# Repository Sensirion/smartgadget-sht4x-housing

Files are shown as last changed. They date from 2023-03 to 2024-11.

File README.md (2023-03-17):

# SHT4x Smartgadget Housing

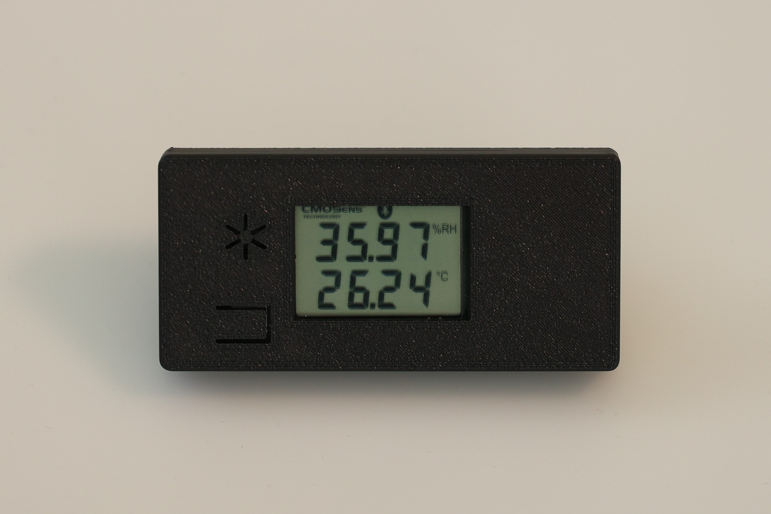
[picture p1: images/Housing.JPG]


## Introduction

The SHT4x Smartgadget is a simple reference design circuit board which demonstrates the outstanding performance and ease of use of Sensirion’s SHT4x Humidity and Temperature sensors. It is equipped with a Liquid Crystal Display (LCD) showing humidity and temperature information. It also features a Bluetooth connection which can be used by smartphones. If you want to buy this gadget or find more information about this sensor, please go to our [Website](https://sensirion.com/products/catalog/SHT4x-Smart-Gadget/).

Since the sensor on the SHT4x Smartgadget is very exposed, a housing was created to better protect it. This guide will show you how to assemble the housing for the SHT4x Smartgadget in order to place it somewhere on your wall or on your desk. In addition, there follows a short sequence describing the influence of the case on the sensor's measurement and what to expect from the SHT4x Smartgadget in the housing. Thus, the guide is structured in these parts:

* [Hardware Setup](#hardware-setup)
    * [Step by Step Assembly](#step-by-step-assembly)
* [Mechanical Integration](#mechanical-integration)
* [Housing Influence on Sensor Reading](#housing-influence-on-sensor-reading)
    * [Introduction](#introduction)
    * [Accuracy](#accuracy)
    * [Response Time](#response-time)

## Hardware Setup

To complete this tutorial you will need:

* SHT4x Smart Gadget
* 3D printed housing of the gadget, consisting of 3 parts (Front, Back and Wall Mount). You can print all these parts yourself (STL files are in the folder "Housing")

### Step by Step Assembly

1. Have the SHT4x Smartgadget (1) ready for assembly and print the Front (2), Back (3) and Wall Mount (4) of the housing:

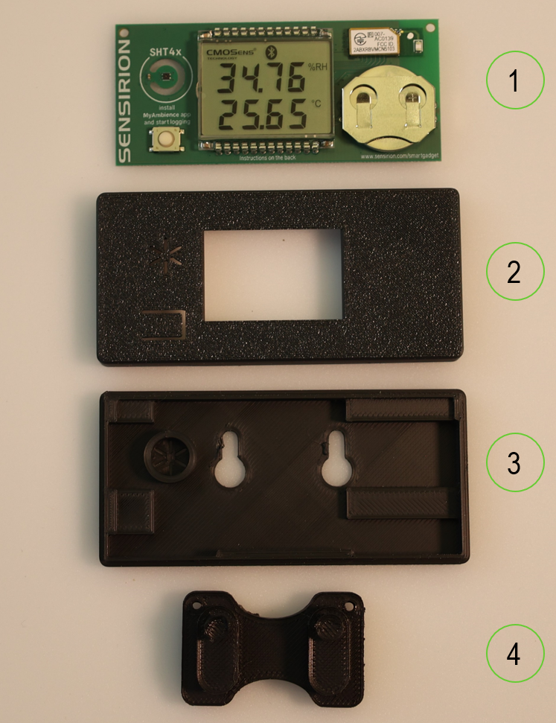
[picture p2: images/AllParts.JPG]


2. Fit the SHT4x Smartgadget into the back wall of the printed housing:

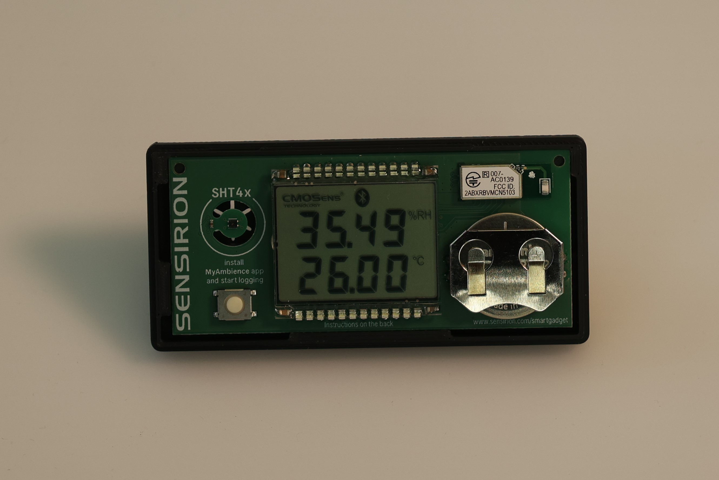
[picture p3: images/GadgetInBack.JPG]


3. Close the housing with the front part:



4. In the end, the wall mount can be attached to the opening at the back and either be attached to the wall or simply used as a stand on your desk:

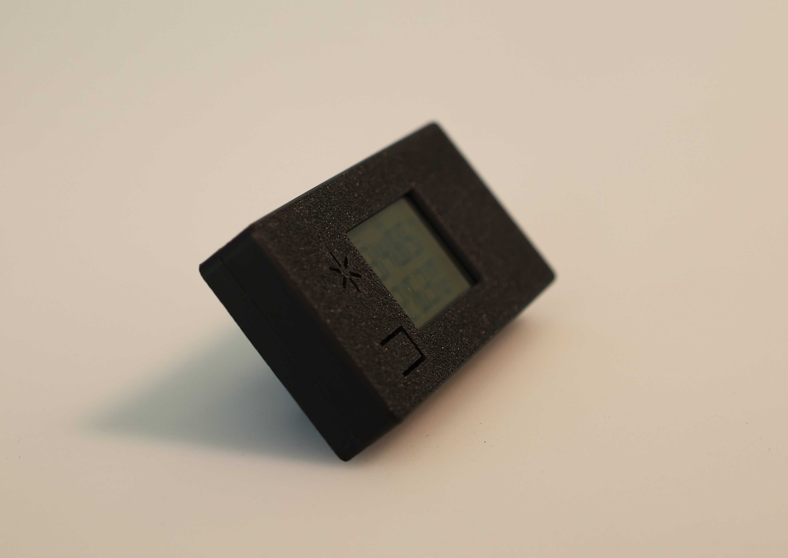
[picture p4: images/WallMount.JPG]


## Mechanical Integration

In order to design such a housing, different requirements need to be met. Firstly and foremost, the sensor readings should be affected minimally by the housing. To do this, the general guide for temperature sensors was followed. The full guide can be found on the [Sensirion Website](https://sensirion.com/media/documents/FC5BED84/61644655/Sensirion_Temperature_Sensors_Design_Guide_V1.pdf). In general, a few things need to be considered. Primarily, the sensor needs to have good access to the environment to allow for air exchange. In addition, the sensor should be sealed from the rest of the compartment to minimize the influence of trapped air inside the housing and only measure the ambient air flow, meaning it should also be decoupled from heat sources like e.g. a microcontroller or the power electronics.

As can be seen from the bare SHT4x Smartgadget Housing in this first picture, the sensor is perfectly decoupled from the rest. The cut-out around the sensor separates the sensor from the rest, hence, allowing for optimal air flow.

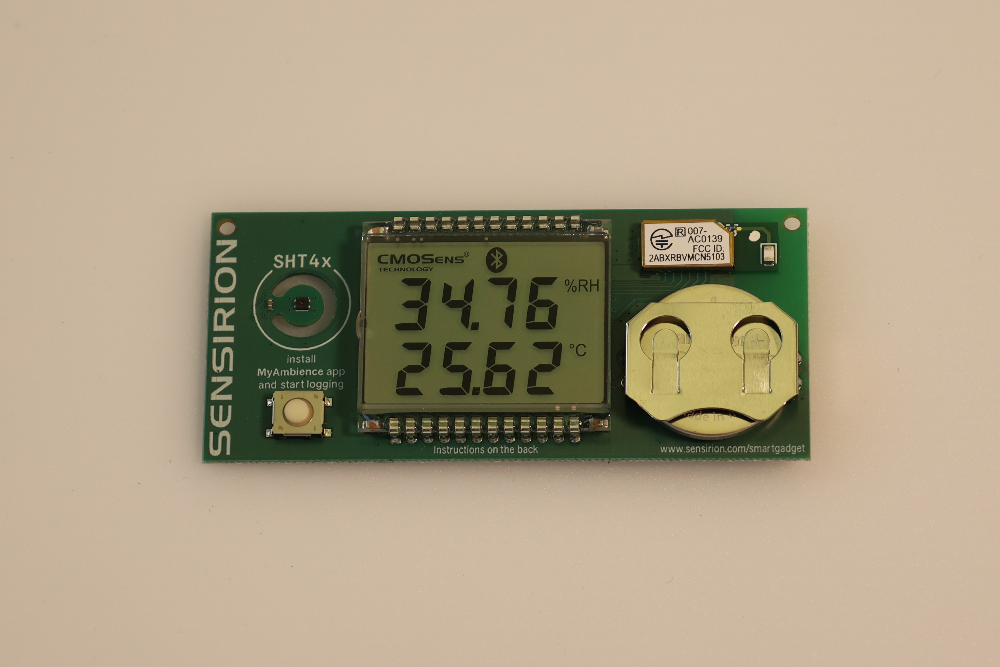
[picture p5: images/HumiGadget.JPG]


To ensure that this encapsulation still holds in the housing, a cylinder was implemented around the sensor. With this implementation, the sensor should only be affected by the ambient conditions. As it was not clear what design of the opening was better for the specifications from the beginning, two designs were made. One which is optically more pleasing with a flower pattern and another one with a hole to guarantee enough air flow to the sensor. Both designs can be seen in the photos below. Both designs were tested and compared to each other at a later stage to define the final case.


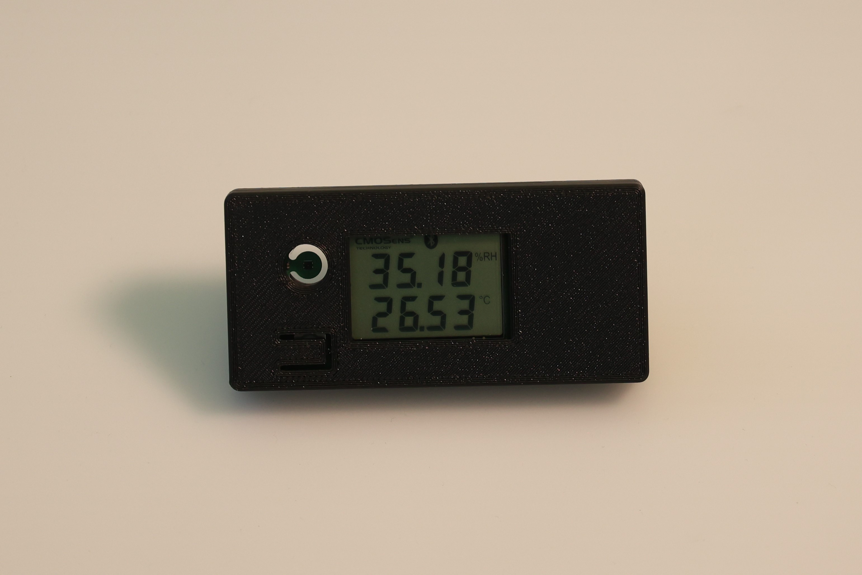
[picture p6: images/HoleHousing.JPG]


## Housing Influence on Sensor Reading

### Introduction

Having a housing around the sensor can influence the accuracy and response time. Thus, the following parts show why and how the sensor readings change due to the housing. Firstly, the accuracy of the sensor might change in a housing depending on how it is coupled to the ambient temperature and how the interaction is between the microcontroller, the power electronics and the sensor itself (especially regarding temperature). In addition, the response time of a sensor can greatly vary when having a case since the housing needs to adapt to the new environment as well and might not change as fast as the ambient conditions. As an example: When you open your window to ventilate your room, the housing around the sensor needs time to adapt to the new temperature and will thus influence the sensor reading as the housing will still have the temperature from before.

**Experimental Conditions**

To test the accuracy of the sensor inside the housing a bare SHT4x and a SHT4x Smartgadgets in the housing the flower opening were set into a temperature chamber at 20, 25 and 30°C where the humidity changed from 40 to 50 to 50% RH in 3h periods. From the sensor readings it could be gathered how good the accuracy is.

In order to test the response time, the temperature response time and the humidity response time were tested separately to exclude mutual influence. For this measurement a bare SHT4x, bare SHT4x Smartgadget, a SHT4x Smartgadget inside the housing with a hole and a SHT4x Smartgadget inside the housing with the flower opening were used. To obtain a temperature response, the temperature chamber was set at 10 °C below ambient while the humidity remained unchanged. After achieving a steady state measurement of the temperature chamber, all sensors were moved out of the chamber and into the ambient to see how quickly they would adjust. Similarly, for humidity, the temperature remained the same as in the ambient, but the humidity was set to 20% higher than in the room. Again, once a stable reading was reached, all sensors were taken out to see how quickly the humidity would adapt.

### Accuracy

The sensor accuracy of a bare SHT4x is $ \pm $ 0.2°C and $\pm$ 2% RH when following the specifications of the datasheet. Thus, looking at the measurement in the graph below, the SHT4x Smartgadget in its housing has the same accuracy as the bare sensor at different temperatures and humidity levels. It can be concluded that the design of the SHT4x Smartgadget does not affect the accuracy of the sensor. The sensor is well decoupled from the microcontroller, so it does not affect the sensor measurement and the housing does not create an additional temperature offset.

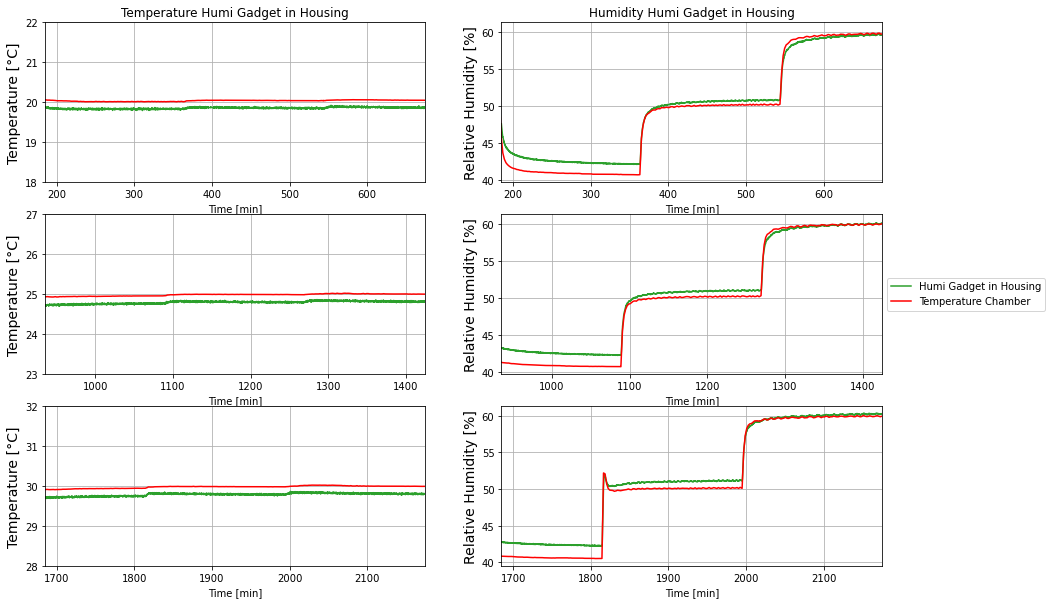
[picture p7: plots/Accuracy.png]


### Response Time

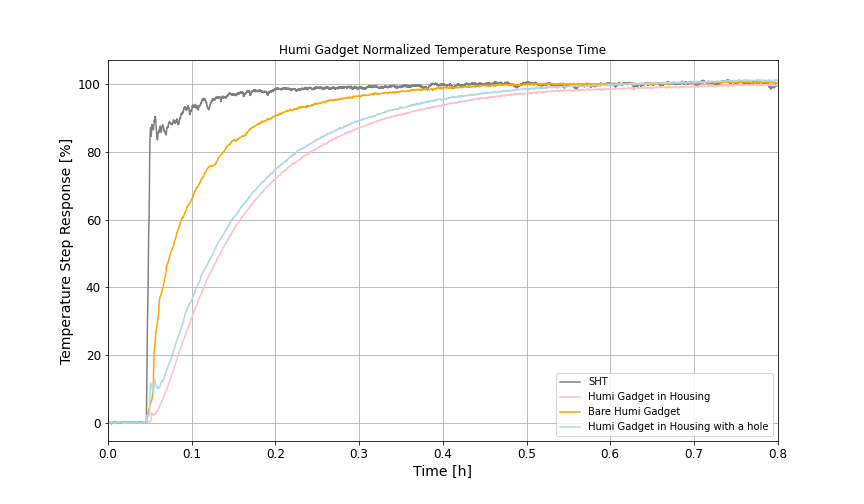
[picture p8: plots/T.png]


As can be seen from the plot above, the housing of the SHT4x Smartgadget has a large influence on the response time of the temperature. But even the bare SHT4x Smartgadget in comparison to the SHT sensor has a large response time difference although the bare SHT4x Smartgadget only has the PCB and a really good coupling of the sensor the the ambient conditions. Then again, when comparing the enclosure with a full hole and without it does not differ a lot. Thus, the full thermal mass of the housing has a much bigger influence on the sensor reading than having a bigger hole above the sensor to have a good ambient coupling.

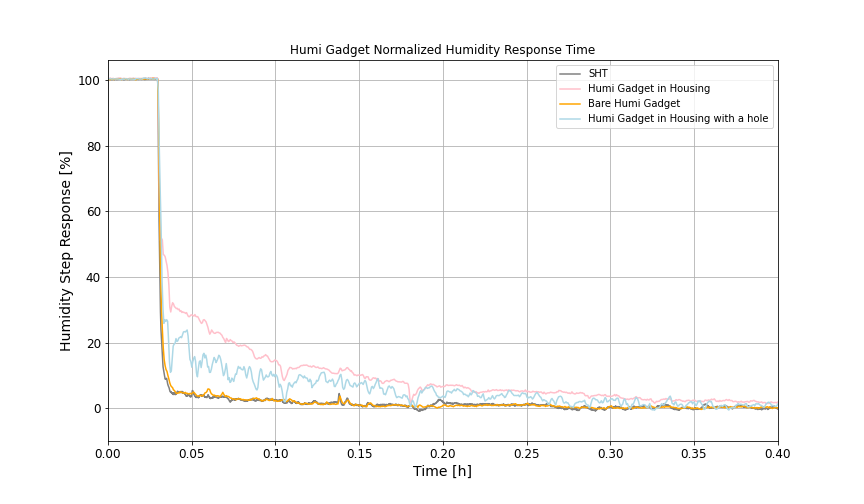
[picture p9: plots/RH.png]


The plot above shows that the opening of the enclosure has a larger influence on the humidity response time than on the temperature response time. Nevertheless, comparing the times between the temperature and humidity response time the temperature response is the bottleneck and is highly effected by the whole housing itself. Thus, when taking the example from above where you would open the window to ventilate your room and measure the new temperature and humidity, the temperature reading will be much slower and thus influence the humidity signal anyways. For this reason, we opted for the case with the nice opening, because all things considered, it doesn't make much of a difference.

### Conclusion

As shown in the previous sections, you now know what you should expect when using the SHT4x Smartgadget with its Housing compared to without it. The housing does not affect the accuracy of the sensor but introduces a longer response time. Thus, when the conditions change rapidly, the sensor will be slower in detecting this change due to the thermal mass of the whole housing. Hence, depending on how you want to utilize the SHT4x Smartgadget, you need to be aware of the drawbacks which come with the housing regarding the response time but nevertheless, the housing gives the sensor a better protection against the weather.

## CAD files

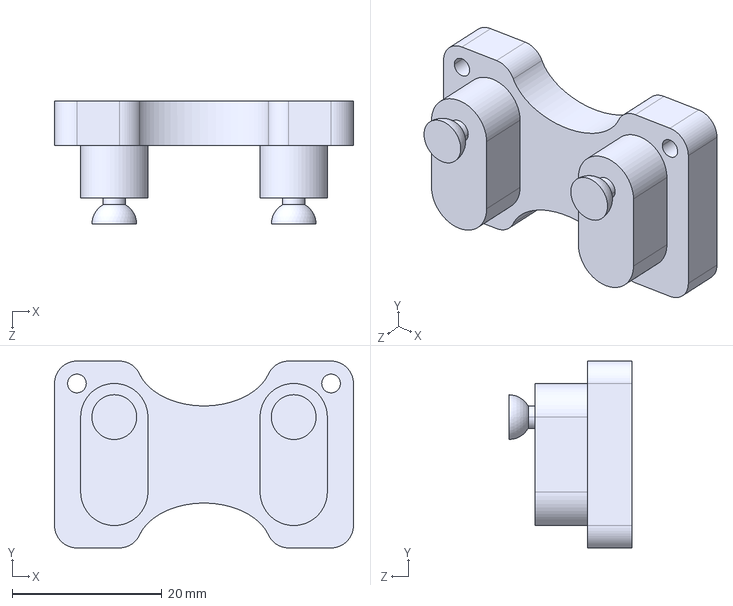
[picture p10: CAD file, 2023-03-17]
Housing/step_files/Housing_Gadget_SHT4x_WallMount.STEP
40.0 x 25.0 x 16.5 mm

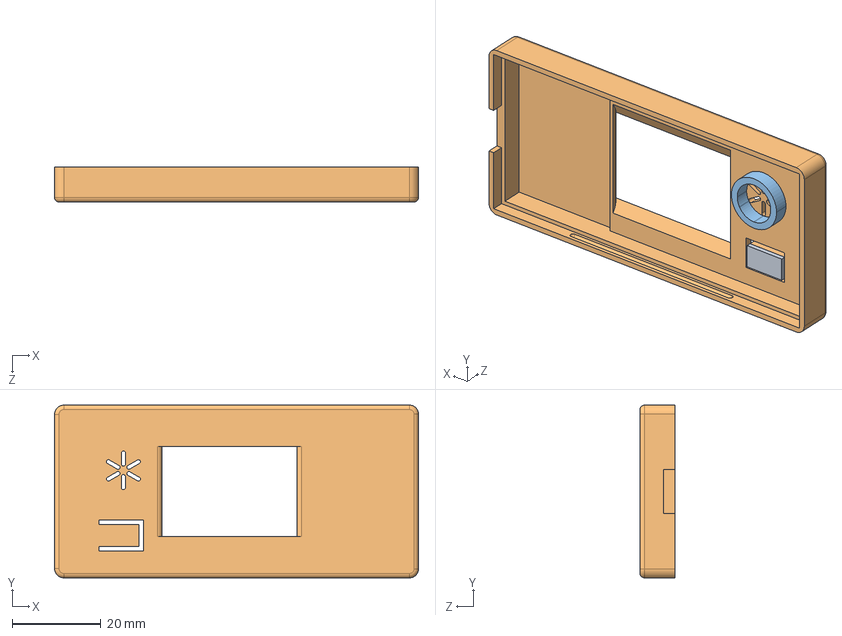
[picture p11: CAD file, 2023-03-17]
Housing/step_files/Housing_Gadget_SHT4x_Front.STEP
81.9 x 38.9 x 7.88 mm

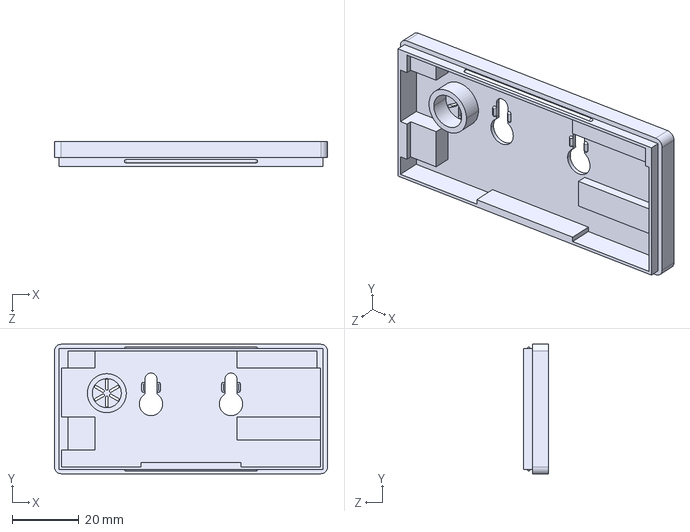
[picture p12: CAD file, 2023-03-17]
Housing/step_files/Housing_Gadget_SHT4x_Back.STEP
81.9 x 38.9 x 7.35 mm

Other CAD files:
Housing/sldprt_files/Housing_Gadget_SHT4x_Back.SLDPRT
Housing/sldprt_files/Housing_Gadget_SHT4x_Front.SLDPRT
Housing/sldprt_files/Housing_Gadget_SHT4x_WallMount.SLDPRT
Housing/stl_files/Housing_Gadget_SHT4x_Back.STL
Housing/stl_files/Housing_Gadget_SHT4x_Front.STL
Housing/stl_files/Housing_Gadget_SHT4x_WallMount.STL

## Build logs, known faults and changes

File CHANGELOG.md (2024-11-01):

# Changelog

All notable changes to this project will be documented in this file.

The format is based on [Keep a Changelog](https://keepachangelog.com/en/1.1.0/),

## [Unreleased]

### Added

- Added SolidWorks design files.

### Changed

- Ensure STL parts have only one body.
- Modified front part to have a thicker wall over the battery.

## [0.1] - 2023-03-17

### Added
- Initial release of the 3D model.
- Release of the study about the impact of the enclosure on the measurements.

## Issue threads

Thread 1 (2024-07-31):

3D print houses refuse to handle the case.

GOTO-GOSUB, 2024-07-31:
Not having access to a 3D printer myself, I have submitted the case (and wall mount) designs to a 3D print house to have them make the parts for me.

The wall mount passes their tests without issue, however they have refused to manufacture both of the case parts. I'm not savvy enough to make their required alterations which I will mention here, in the hope that this might help someone else.

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

qfisch, 2024-08-20:
Hello @GOTO-GOSUB

Apologies for the "slight" delay.
I could not see the issue in the slicer we use in-house but the CAD software indeed showed 2 bodies.
I now modified it a bit and I believe it should work. Can you check it out with the fab ?
[Housing_Gadget_SHT4x_Front_modified.zip](https://github.com/user-attachments/files/16675335/Housing_Gadget_SHT4x_Front_modified.zip)

Cheers
Q.

GOTO-GOSUB, 2024-09-04:
Thank you for the updated file - I have just submitted it to my fabricator. I will post back with the outcome.

GOTO-GOSUB, 2024-09-11:
Hi @qfisch ,

Thanks again for the updated file. That passed the 3D fab's ingest test with a warning about wall thickness, but apart from that making for a slightly wonky fit that will probably straighten itself out over time the case fits OK. Now I've got a few of these in my hands there is another issue. The front of the case that covers the battery is tissue paper thin, so thin in fact that I can read through it and it has almost no tensile strength. Can this please be made bit thicker ? It's probably OK for static gadgets that are out of reach but I doubt it will stand up to repeated handling. Someone - probably me - is going to put their finger through these:

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

qfisch, 2024-09-11:
Hello @GOTO-GOSUB.

My apologies for the trouble, I do not understand what happened between the testing of the case and the publication here.
I need to investigate a bit in order to find who designed it.
We need to make some checks about that model.
I will come back to you once as soon as I get more info

Sorry again
Q.

GOTO-GOSUB, 2024-09-11:
No problem, thank you for looking into it. I will wait on your findings.

qfisch, 2024-10-22:
Hello @GOTO-GOSUB ,
I finally put my hands on the original model and the wall thickness is indeed set to 0.53mm.
Depending on the printer's ability it will indeed give a pretty fragile shell.

I have no time to edit the file unfortunately, but I will post the design files so one can modify them.

Cheers
Q

qfisch, 2024-11-01:
Hello @GOTO-GOSUB ,
I now made the changes required to have a thicker shell over the battery.
I doubled it to 1mm, I hope you won't have further issues with it.

Cheers
Q

GOTO-GOSUB, 2024-11-01:
Thanks, @qfisch - I do not have the skill-set to do that myself. As soon as I have enough work to justify another order with my 3D printing house I will get these remade and update this ticket.

GOTO-GOSUB, 2024-11-06:
Hi @qfisch ,

I have just had these back from my print house - the changes that you made have resolved this issue.

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

Thanks again.

Closed 2024-10-22.

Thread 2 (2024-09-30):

import failed to translate

trenGit, 2024-09-30:
Hello, i tried to import these file into Onshape CAD program and they fail to translate do you have a different file type that may be editable in a cad program? thank you

qfisch, 2024-10-07:
Hello @trenGit ,

We made a mistake when uploading the design files and we are currently looking for the correct files that will allow anybody to open/edit.

_Please note that the housing was designed on SolidWorks, therefore the files might not be completely compatible with other software._

I will update you as soon as I know more.

Cheers
Q.

trenGit, 2024-10-21:
very excited to be able to play/ customize with the CAD file. still getting used to various CAD software and i am learning to use the various SHT sensors now. they are very small and i am not used to soldering in this microscopic scale. i whish the smart gadget came with the sht45 chip but i will try to swap the sht40 for the sht45 some other time. thanks!

qfisch, 2024-10-22:
Hello @trenGit
The [PR #4 ](https://github.com/Sensirion/smartgadget-sht4x-housing/pull/4/)will provide you the design files.
These are SolidWorks files but hopefully you can import them in your CAD software of choice.

Cheers
Q

trenGit, 2024-10-22:
@qfisch thank you so much !

Closed 2024-10-22.

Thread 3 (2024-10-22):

Too thin shell over battery

qfisch, 2024-10-22:
The shell design is **only .53mm** over the battery which can be too fragile if the printer used is actually printing that thickness.
Thanks @GOTO-GOSUB for raising the issue [here](https://github.com/Sensirion/smartgadget-sht4x-housing/issues/1#issuecomment-2343538839).

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

Closed 2024-11-01.

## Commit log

2023-03-17 initial upload
    [Housing_Gadget_SHT4x_Back.STEP, Housing_Gadget_SHT4x_Back.STL, Housing_Gadget_SHT4x_Front.STEP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]
2024-10-22 organized Housing folder
    [Housing_Gadget_SHT4x_Back.STEP, Housing_Gadget_SHT4x_Back.STL, Housing_Gadget_SHT4x_Front.STEP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]
2024-10-22 Fix 2 body problem in front STL file
    [Housing_Gadget_SHT4x_Front.STL]
2024-10-22 added solidworks design files
    [Housing_Gadget_SHT4x_Back.SLDPRT, Housing_Gadget_SHT4x_Front.SLDPRT, Housing_Gadget_SHT4x_WallMount.SLDPRT]
2024-11-01 modified front piece to have a thicker wall over battery
    [Housing_Gadget_SHT4x_Front.SLDPRT, Housing_Gadget_SHT4x_Front.STL]
